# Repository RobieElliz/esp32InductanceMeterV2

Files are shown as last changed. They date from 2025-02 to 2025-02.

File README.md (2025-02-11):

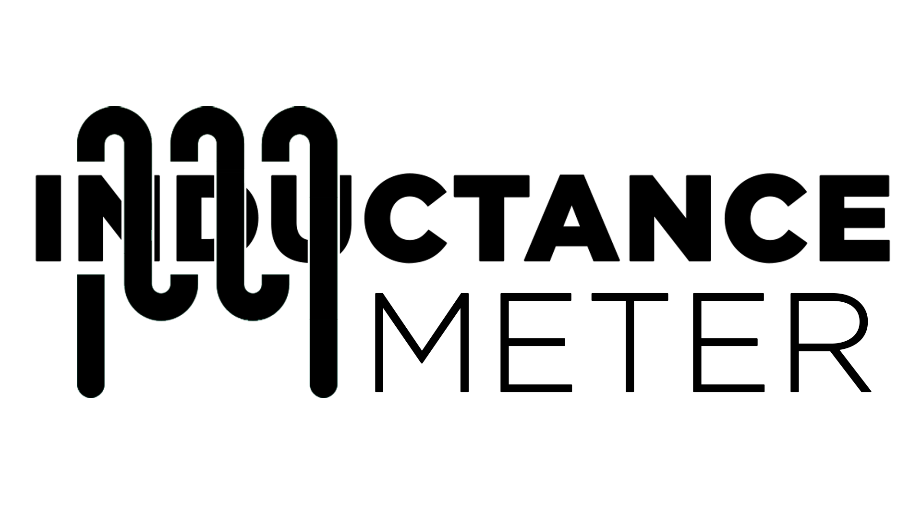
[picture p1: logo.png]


# Portable ESP32 Inductance Meter

A DIY ESP32-based inductance meter designed to bridge the gap in electronics testing. Developed at the Polytechnic University of the Philippines, this low-cost, high-precision tool is ideal for students, researchers, and hobbyists.

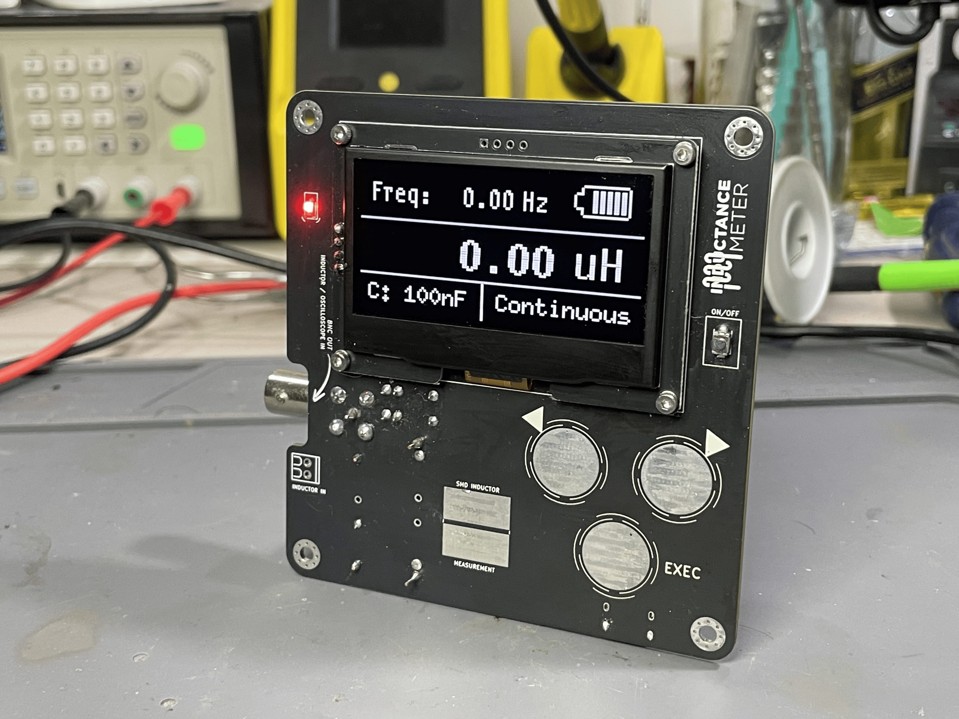
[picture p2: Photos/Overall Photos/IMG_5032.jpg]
Inductance Meter Overview


---

## 🔧 Bridging the Gap in Electronics Testing

Accurate inductance measurement is crucial in electronics. Yet, professional meters are often expensive and inaccessible. This project provides an affordable alternative for educational and experimental applications.

---

## 🚀 What It Does

Using LC resonance principles, the device:
- Excites inductors and detects oscillations
- Calculates inductance with high accuracy
- Measures various types of inductors:
  - Toroidal
  - Power
  - Surface-mount (SMD)
  - Air-core  
- Employs dual reference capacitors (100nF & 5µF) for precise mH and µH readings

---

## 🛠 Key Features & Innovations

- **ESP32-powered processing** for real-time calculations  
- **Dual reference capacitors** to optimize accuracy  
- **Capacitive touch controls** for seamless operation  
- **Rechargeable 18650 battery** for true portability  
- **OLED display** for clear, instant readings  
- **Multiple measurement modes:** Single or continuous testing

---

## 📌 Why It Matters

By democratizing access to essential testing equipment, this project empowers the next generation of engineers to innovate and experiment without breaking the bank.

---

## Detailed Components

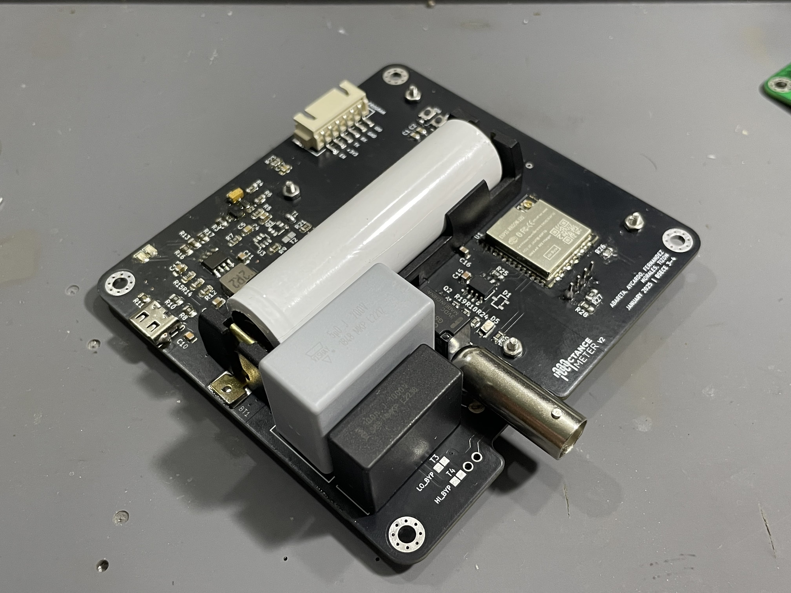
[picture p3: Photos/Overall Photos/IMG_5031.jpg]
Detailed Components


### 🔧 Dual Reference Capacitors (100nF & 5µF)
- **100nF:** For higher inductance (mH range) with enhanced accuracy  
- **5µF:** Ideal for lower inductance (µH range) ensuring frequency stability

### 🟢 TLV3202 Comparator
- Ultra-high-speed and low-power
- Ensures precise detection of LC oscillations

### ⚡ IP2312 Battery Management IC
- Supports USB Type-C charging (5V, up to 3A)
- Provides overvoltage, undervoltage, and overcurrent protection
- Delivers a stable 3.3V output with buck-boost regulation

### 📟 2.4-inch OLED Display
- Connected via I²C for reduced wiring complexity
- Stacked on the PCB using screws for a compact design
- Displays real-time inductance, frequency, and battery status

---

## Additional Resources

- **OLED Module Purchase:**  
  [Shopee: 2.4" 2.42 inch 128x64 OLED LCD Display Module SSD1309](https://shopee.ph/2.4-2.42-inch-128x64-OLED-LCD-Display-Module-SSD1309-12864-7-Pin-SPI-IIC-I2C-Serial-Interface-for-Arduino-UNO-R3-C51-i.517103615.18774113725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)

---

## License

This project is open source. See the [LICENSE](LICENSE) file for more details.

---

## Made By

This project is made by:  
Johanna Abareta, Ken Louise Aycardo, Katrina Dianne Fernandez, Vince Morales, Robie Elliz Tizon

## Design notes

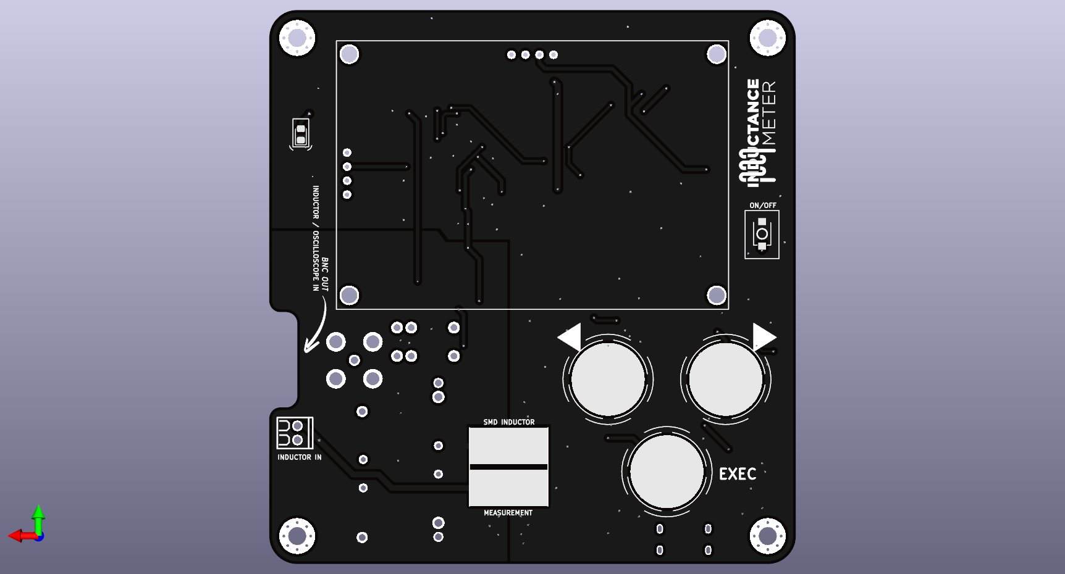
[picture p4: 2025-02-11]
Photos/KiCad PCB Photos/Front-Bare.png

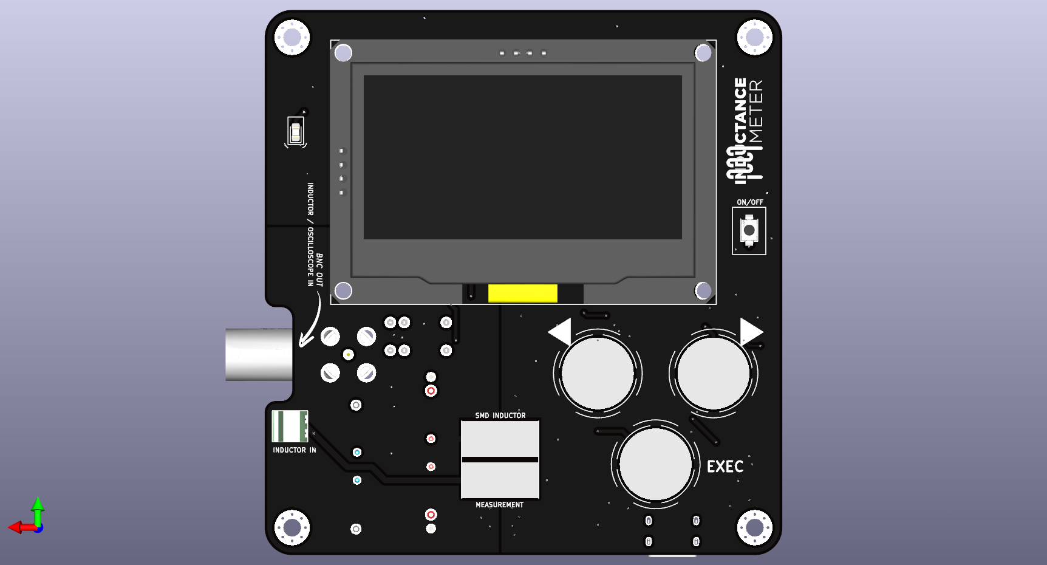
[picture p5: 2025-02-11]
Photos/KiCad PCB Photos/Front.png

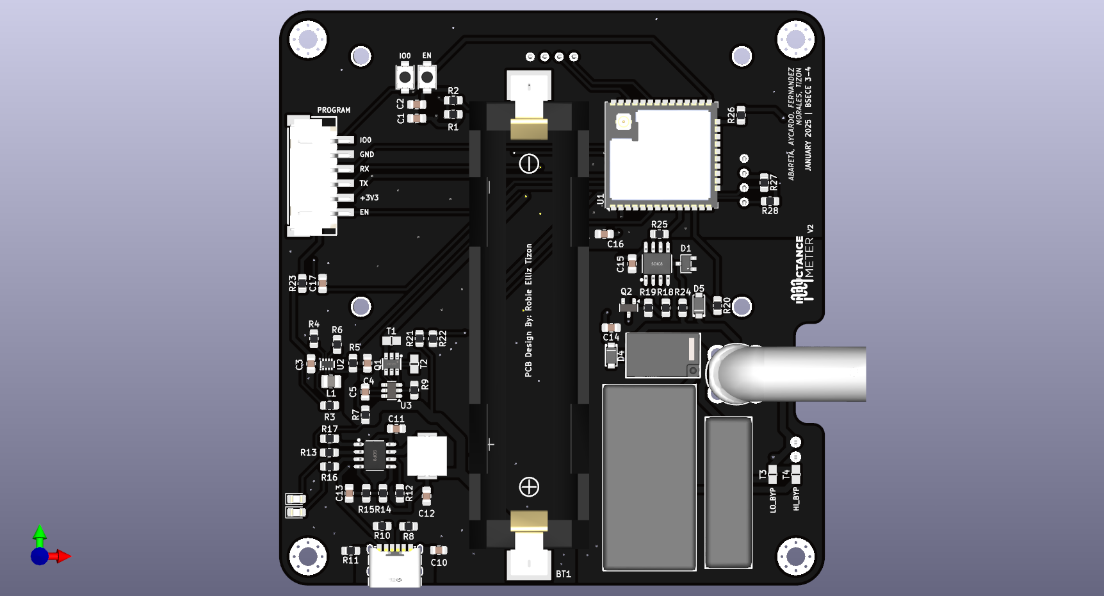
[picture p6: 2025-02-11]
Photos/KiCad PCB Photos/Back.png

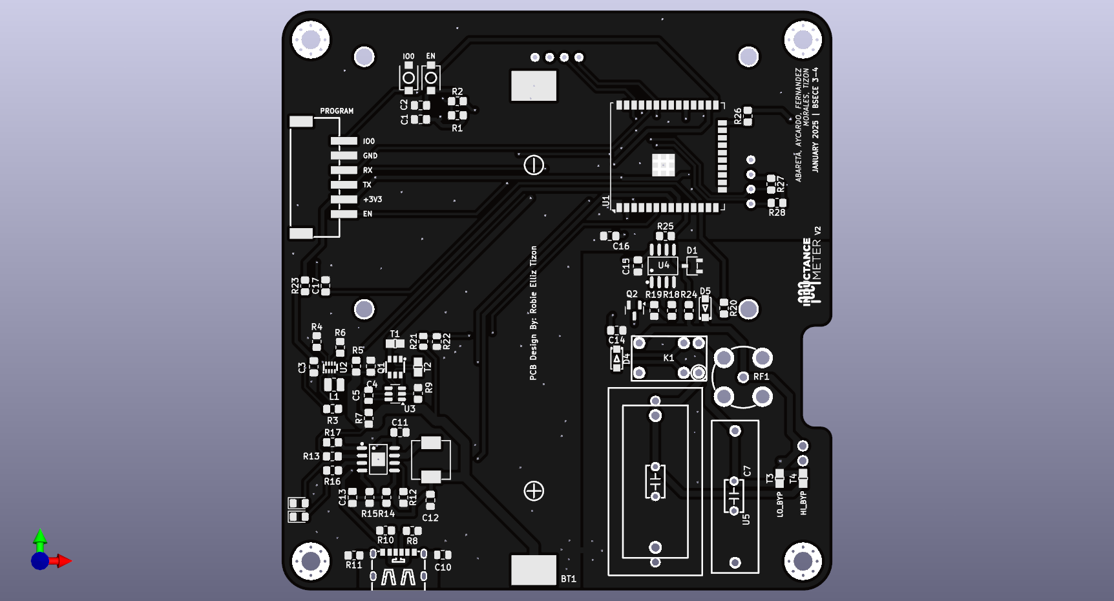
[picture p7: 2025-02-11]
Photos/KiCad PCB Photos/Back-Bare.png

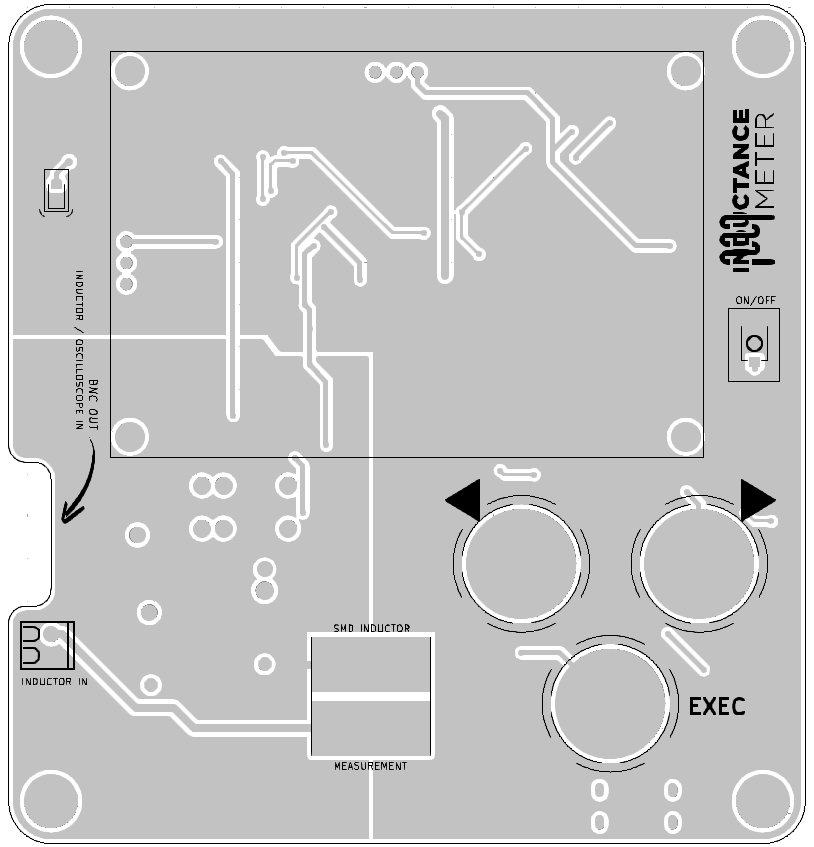
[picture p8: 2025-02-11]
Photos/KiCad PCB Photos/Front PCB Layout.png

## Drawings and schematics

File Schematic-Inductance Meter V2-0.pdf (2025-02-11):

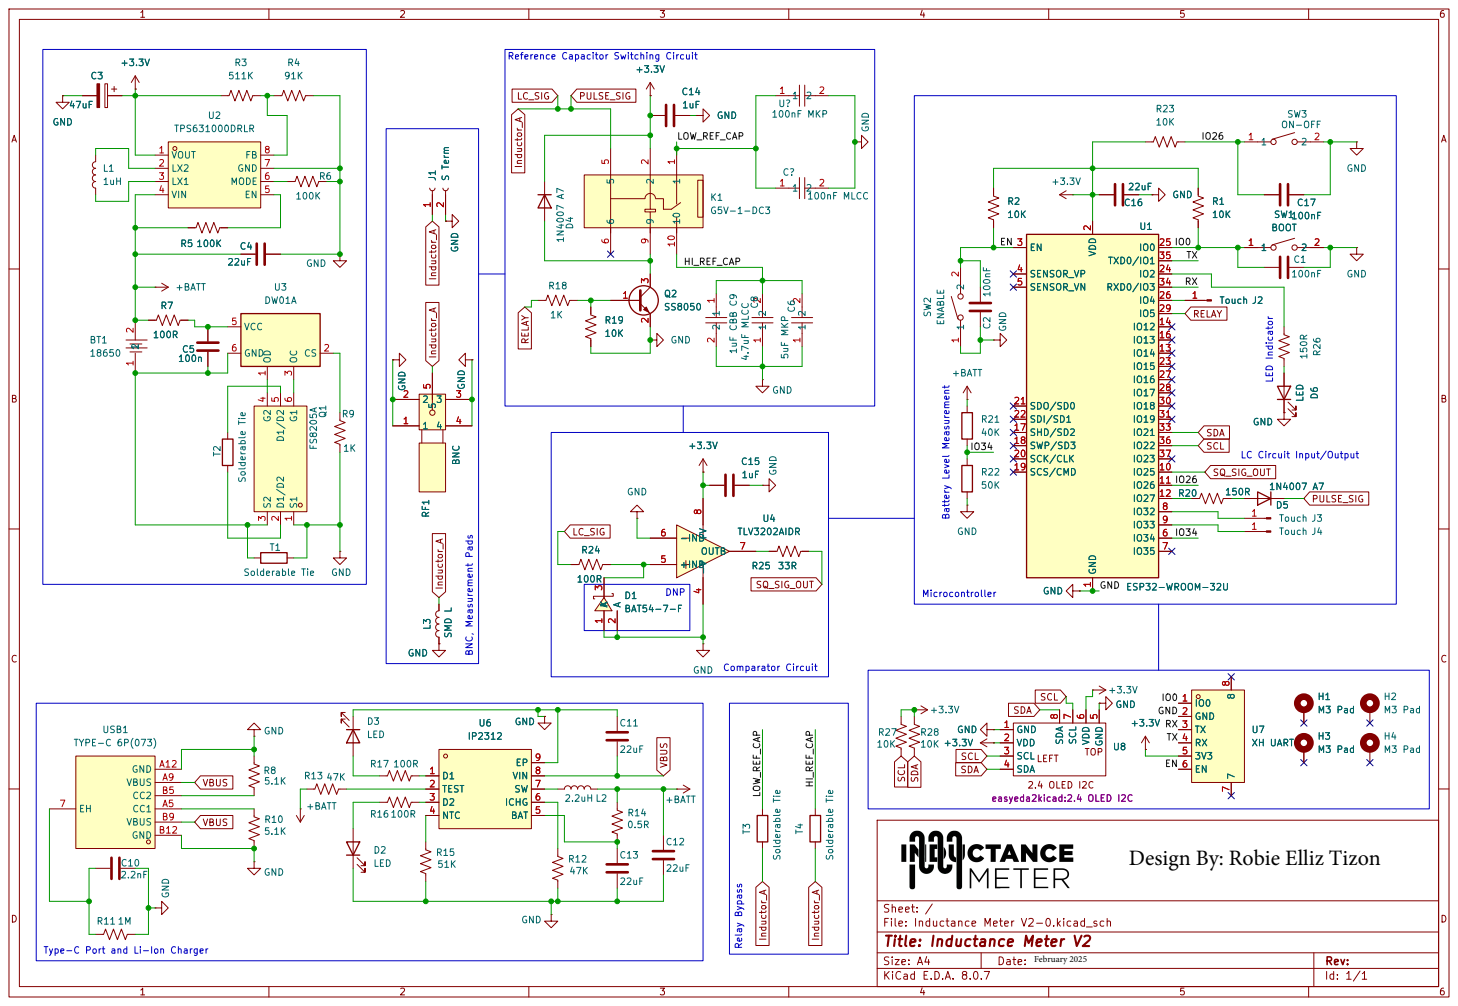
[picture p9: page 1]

2 SCK/CLK 20 SDO/SD0 21 SDI/SD1 22

Design By: Robie Elliz Tizon

Id: 1/1 Title: Inductance Meter V2

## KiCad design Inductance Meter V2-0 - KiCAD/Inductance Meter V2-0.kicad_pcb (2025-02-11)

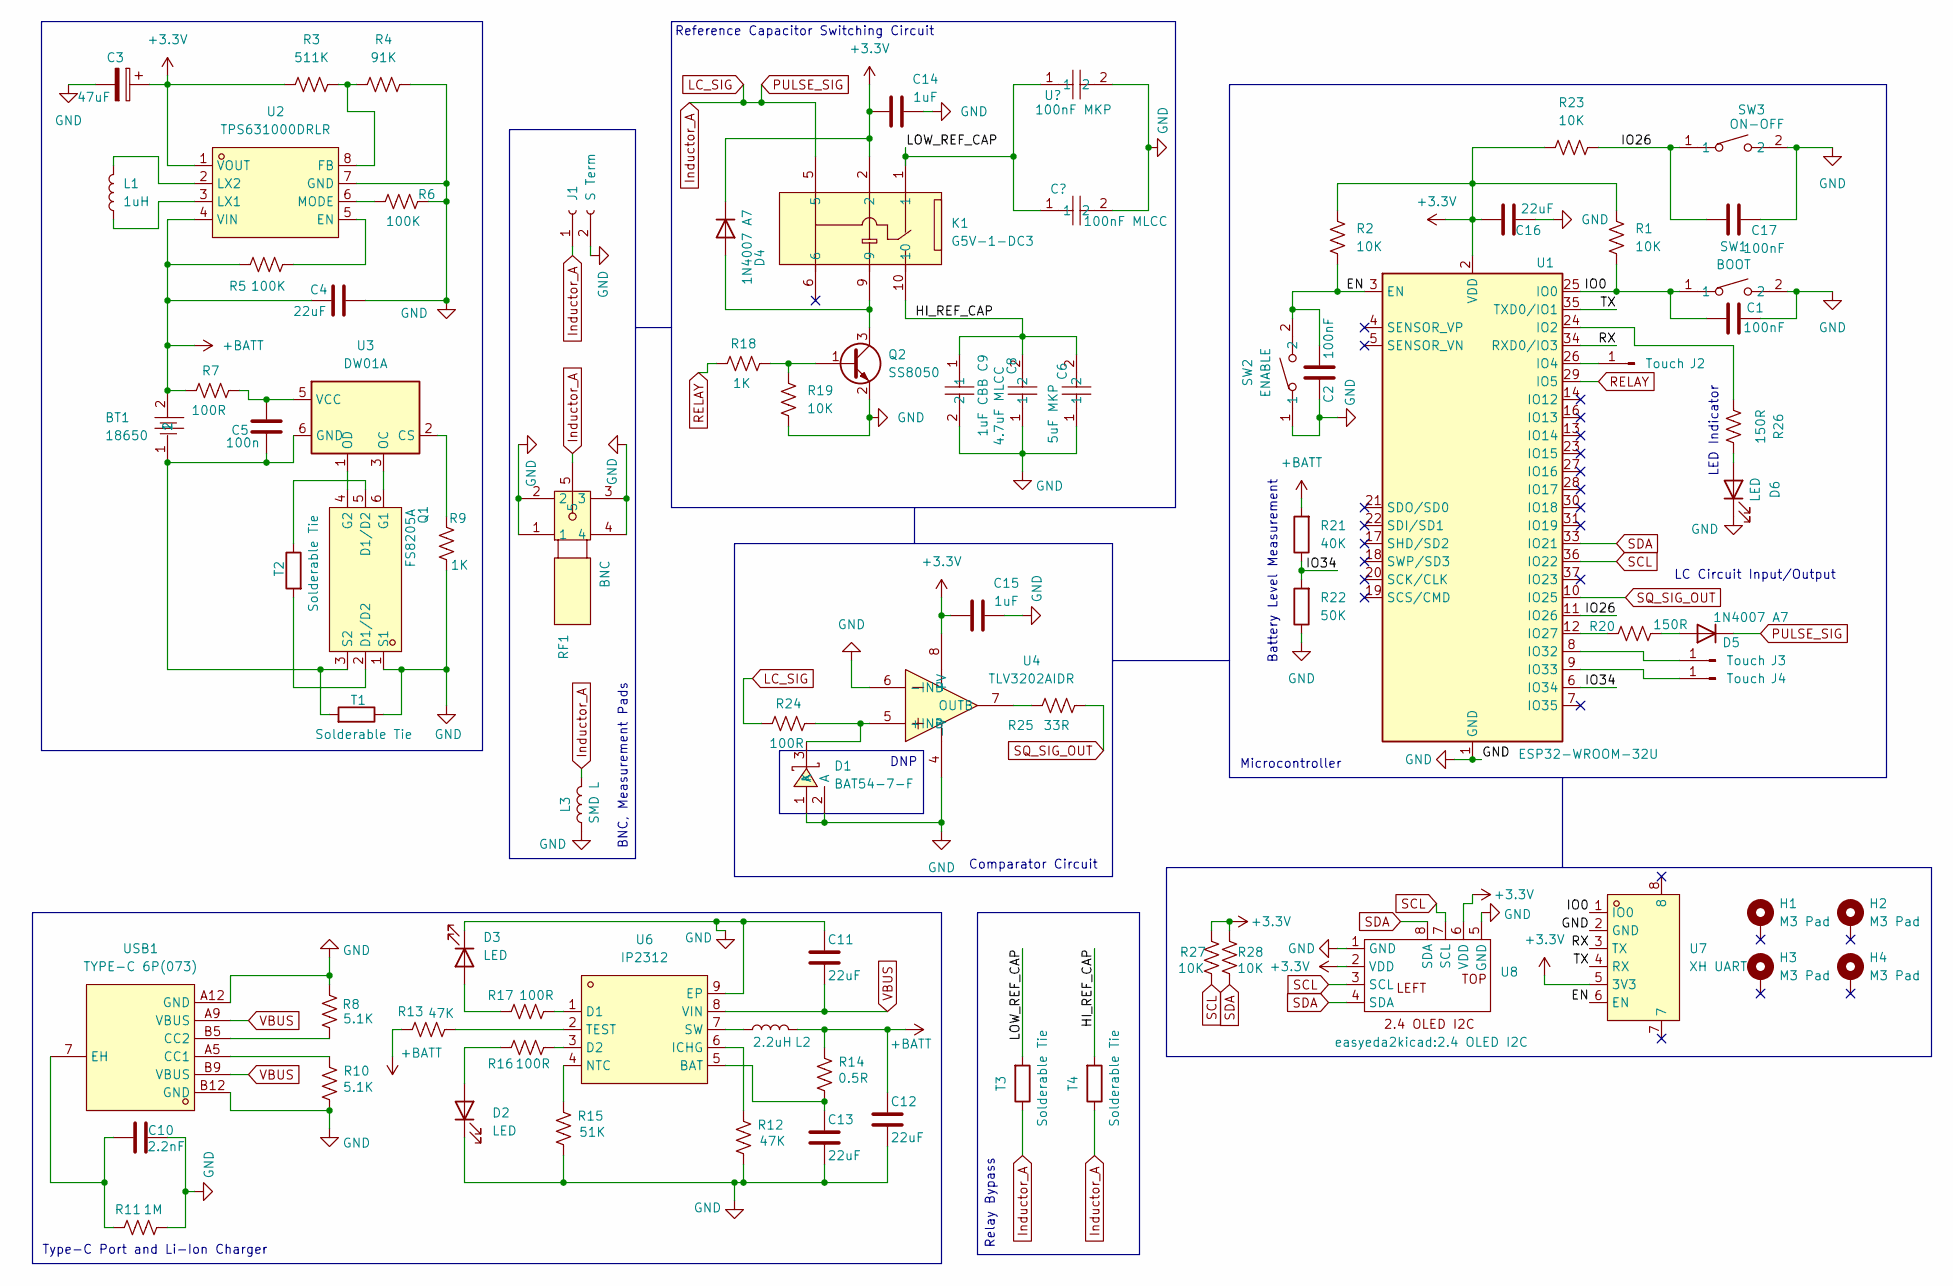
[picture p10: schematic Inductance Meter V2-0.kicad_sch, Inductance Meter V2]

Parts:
BT1: 18650; BATTERY-SMD_18650-1S-L77.1-W20.7-1; LCSC Part C2988620
C1, C2, C17: 100nF; C_0805_2012Metric_Pad1.18x1.45mm_HandSolder
C3: 47uF; C_0805_2012Metric_Pad1.18x1.45mm_HandSolder
C4, C11, C12, C13, C16: 22uF; C_0805_2012Metric_Pad1.18x1.45mm_HandSolder
C5: 100n; C_0805_2012Metric
C6: 5uF MKP; CAP-TH_L32.0-W16.0-P27.50-D0.8; LCSC Part C3803313
C8: 4.7uF MLCC; CAP-TH_L5.5-W3.2-P5.00-D0.5; LCSC Part C907942
C9: 1uF CBB; CAP-TH_L26.0-W11.1-P22.50-D1.4; LCSC Part C178465
C10: 2.2nF; C_0805_2012Metric
C14, C15: 1uF; C_0805_2012Metric_Pad1.18x1.45mm_HandSolder
D1: BAT54-7-F; SOT-23-3_L2.9-W1.6-P1.90-LS2.8-BR; LCSC Part C106920
D2, D3, D6: LED; LED_0805_2012Metric_Pad1.15x1.40mm_HandSolder
D4, D5: 1N4007 A7; SOD-123FL_L2.8-W1.8-LS3.7-RD
H1, H2, H3, H4: M3 Pad; MountingHole_3.2mm_M3_Pad_Via
J1: S Term; CONN-TH_2P-P2.54_MX128-2.54-GN01-02P-CU-Y-A
J2, J3, J4: Touch; Touch_Pad_ESP
K1: G5V-1-DC3; RELAY-TH_G5V-1; LCSC Part C397232
L1: 1uH; L_1008_2520Metric
L2: 2.2uH; IND-SMD_L7.1-W6.6; LCSC Part C2847481
L3: SMD L; IND-SMD_L7.1-W6.6; LCSC Part C2847481
Q1: FS8205A; SOT-23-6_L2.9-W1.6-P0.95-LS2.8-BR; LCSC Part C2830320
Q2: SS8050; SOT-23
R1, R2, R19, R23, R27, R28: 10K; R_0805_2012Metric_Pad1.20x1.40mm_HandSolder
R3: 511K; R_0805_2012Metric_Pad1.20x1.40mm_HandSolder
R4: 91K; R_0805_2012Metric_Pad1.20x1.40mm_HandSolder
R5, R6: 100K; R_0805_2012Metric_Pad1.20x1.40mm_HandSolder
R7, R16, R17, R24: 100R; R_0805_2012Metric_Pad1.20x1.40mm_HandSolder
R8, R10: 5.1K; R_0805_2012Metric_Pad1.20x1.40mm_HandSolder
R9, R18: 1K; R_0805_2012Metric_Pad1.20x1.40mm_HandSolder
R11: 1M; R_0805_2012Metric_Pad1.20x1.40mm_HandSolder
R12, R13: 47K; R_0805_2012Metric_Pad1.20x1.40mm_HandSolder
R14: 0.5R; R_0805_2012Metric_Pad1.20x1.40mm_HandSolder
R15: 51K; R_0805_2012Metric_Pad1.20x1.40mm_HandSolder
R20, R26: 150R; R_0805_2012Metric_Pad1.20x1.40mm_HandSolder
R21: 40K; R_0805_2012Metric
R22: 50K; R_0805_2012Metric
R25: 33R; R_0805_2012Metric_Pad1.20x1.40mm_HandSolder
RF1: BNC; BNC-TH_DOSIN-801-0051; LCSC Part C521210
SW1: BOOT; SW-SMD_L3.9-W3.0-P4.45; LCSC Part C720477
SW2: ENABLE; SW-SMD_L3.9-W3.0-P4.45; LCSC Part C720477
SW3: ON-OFF; SW-SMD_L3.9-W3.0-P4.45; LCSC Part C720477
T1, T2, T3, T4: Solderable Tie; Net-Tie 0805 Based
U1: ESP32-WROOM-32U
U2: TPS631000DRLR; SOT-583-8_L2.1-W1.2-P0.50-LS1.6-BL; LCSC Part C5219190
U3: DW01A; SOT-23-6
U4: TLV3202AIDR; SOIC-8_L4.9-W3.9-P1.27-LS6.0-BL; LCSC Part C129325
U6: IP2312; SOP-8_L4.9-W3.9-P1.27-LS6.0-BL-EP; LCSC Part C605432
U7: XH UART; CONN-SMD_S6B-XH-SM4-TB-LF-SN; LCSC Part C191914
U8: 2.4 OLED I2C
USB1: TYPE-C 6P(073); TYPE-C-SMD_TYPE-C-6P_5; LCSC Part C668623

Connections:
+3.3V: C3.1, C14.2, C15.2, C16.2, D4.1 (K), K1.2, R1.1, R2.1, R3.1, R23.2, R27.1, R28.1, U1.2 (VDD), U2.1 (VOUT), U4.8 (+V), U7.5 (3V3), U8.2 (VDD), U8.6 (VDD)
+BATT: BT1.2, C4.1, C12.2, L2.2, R5.1, R7.1, R13.1, R14.1, R21.2, U2.4 (VIN)
/EN: C2.2, R2.2, SW2.2, U1.3 (EN), U7.6 (EN)
/HI_REF_CAP: C6.2, C8.2, C9.1, K1.10, T4.1
/IO0: C1.1, R1.2, SW1.1, U1.25 (IO0), U7.1 (IO0)
/IO2: R26.1, U1.24 (IO2)
/IO26: C17.1, R23.1, SW3.1, U1.11 (IO26)
/IO34: R21.1, R22.2, U1.6 (IO34)
/LOW_REF_CAP: K1.1, T3.1; also elsewhere on the board
/RX: U1.34 (RXD0/IO3), U7.3 (TX)
/TX: U1.35 (TXD0/IO1), U7.4 (RX)
GND: C1.2, C2.1, C3.2, C4.2, C6.1, C8.1, C9.2, C10.2, C11.2, C12.1, C13.1, C14.1, C15.1, C16.1, C17.2, D1.1 (A), D1.2 (A), D2.1 (K), D3.1 (K), D6.1 (K), J1.2, L3.1, Q1.1 (S1), Q2.2 (E), R4.2, R6.2, R8.2, R9.2, R10.2, R11.2, R12.2, R15.2, R19.1, R22.1, RF1.1, RF1.2, RF1.3, RF1.4, SW1.2, SW2.1, SW3.2, T1.2, U1.1 (GND), U1.15 (GND), U1.38 (GND), U1.39 (GND), U2.7 (GND), U4.4 (-V), U4.6 (-INB), U6.9 (EP), U7.2 (GND), U8.1 (GND), U8.5 (GND), USB1.A12 (GND), USB1.B12 (GND); also elsewhere on the board
Inductor_A: D5.1 (K), J1.1, K1.5, L3.2, R24.1, RF1.5, T3.2, T4.2
unnamed: D1.3 (K), R24.2, U4.5 (+INB)
unnamed: D2.2 (A), R16.1
unnamed: D3.2 (A), R17.1
unnamed: D4.2 (A), K1.9, Q2.3 (C)
unnamed: D5.2 (A), R20.2
unnamed: D6.2 (A), R26.2
unnamed: J2.1, U1.26 (IO4)
unnamed: J3.1, U1.8 (IO32)
unnamed: J4.1, U1.9 (IO33)
unnamed: Q1.2 (D1/D2), T2.1
unnamed: Q1.5 (D1/D2), T2.2
unnamed: Q1.6 (G1), U3.3 (OC)
unnamed: Q1.4 (G2), U3.1 (OD)
unnamed: BT1.1, C5.2, Q1.3 (S2), T1.1, U3.6 (GND)
unnamed: Q2.1 (B), R18.2, R19.2
unnamed: R20.1, U1.12 (IO27)
unnamed: R5.2, U2.5 (EN)
unnamed: R3.2, R4.1, U2.8 (FB)
unnamed: L1.1, U2.3 (LX1)
unnamed: L1.2, U2.2 (LX2)
unnamed: R6.1, U2.6 (MODE)
unnamed: R9.1, U3.2 (CS)
unnamed: C5.1, R7.2, U3.5 (VCC)
unnamed: R25.1, U4.7 (OUTB)
unnamed: C13.2, R14.2, U6.5 (BAT)
unnamed: R17.2, U6.1 (D1)
unnamed: R16.2, U6.3 (D2)
unnamed: R12.1, U6.6 (ICHG)
unnamed: R15.1, U6.4 (NTC)
unnamed: L2.1, U6.7 (SW)
unnamed: R13.2, U6.2 (TEST)
unnamed: R10.1, USB1.A5 (CC1)
unnamed: R8.1, USB1.B5 (CC2)
unnamed: C10.1, R11.1, USB1.7 (EH)
RELAY: R18.1, U1.29 (IO5)
SCL: R27.2, U1.36 (IO22), U8.3 (SCL), U8.7 (SCL)
SDA: R28.2, U1.33 (IO21), U8.4 (SDA), U8.8 (SDA)
SQ_SIG_OUT: R25.2, U1.10 (IO25)
VBUS: C11.1, U6.8 (VIN), USB1.A9 (VBUS), USB1.B9 (VBUS)

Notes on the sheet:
LC Circuit Input/Output
Reference Capacitor Switching Circuit
Battery Level Measurement
BNC, Measurement Pads
Type-C Port and Li-Ion Charger
Microcontroller
Comparator Circuit
Relay Bypass
DNP
LED Indicator

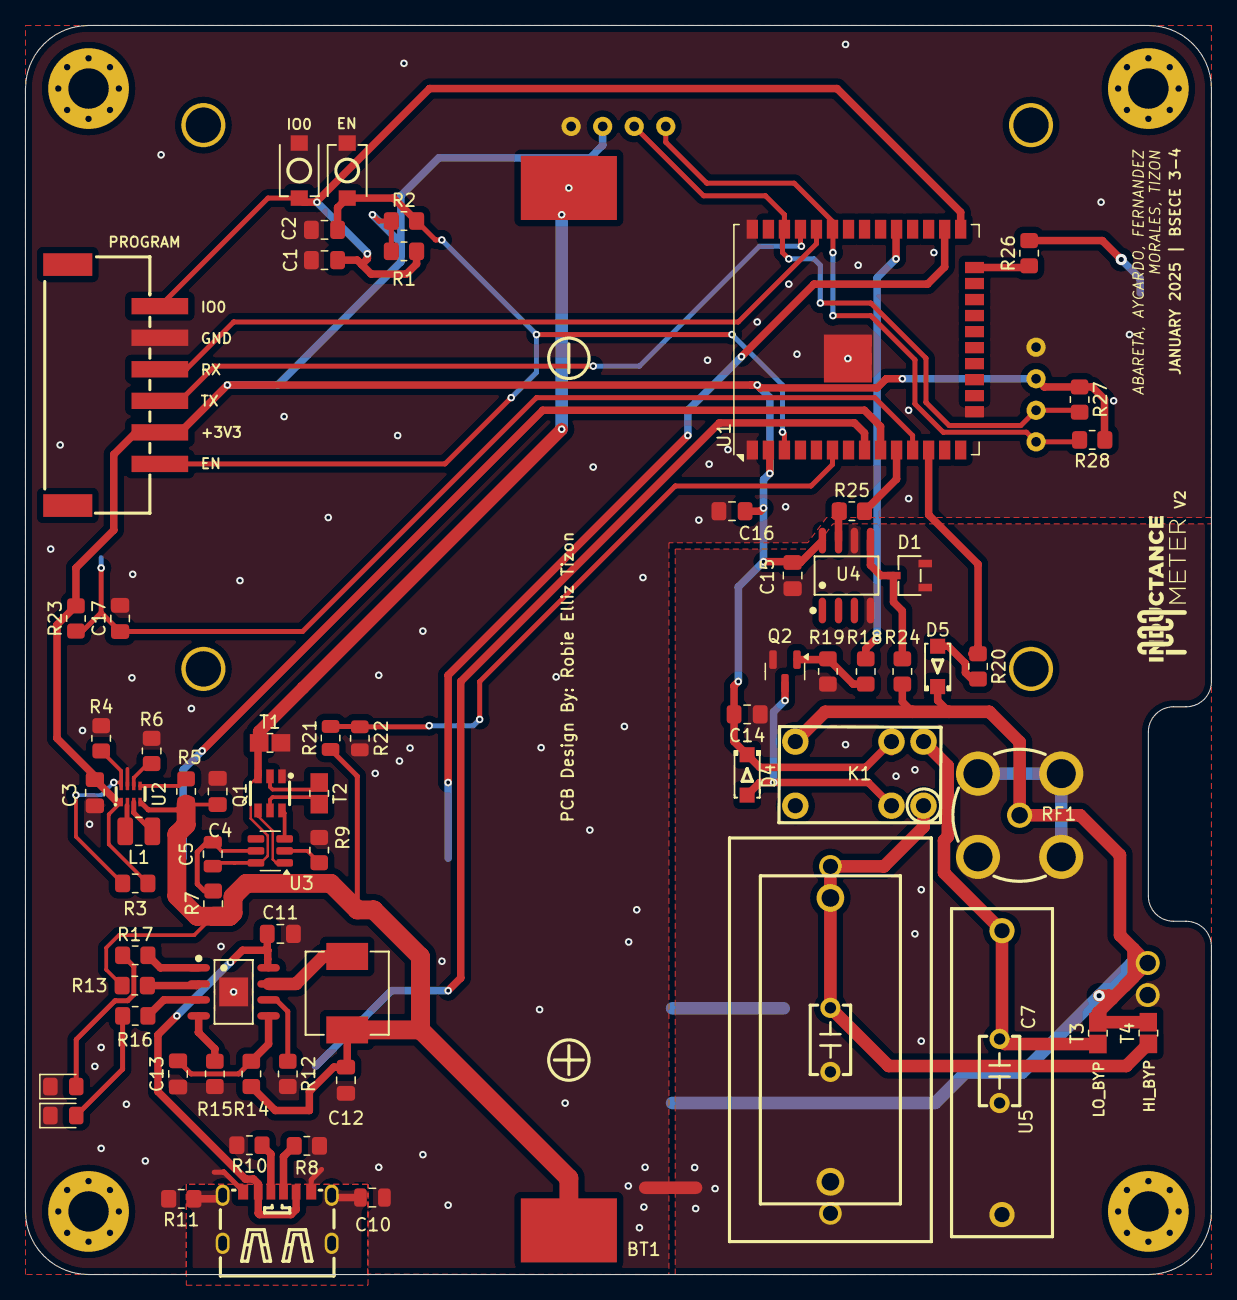
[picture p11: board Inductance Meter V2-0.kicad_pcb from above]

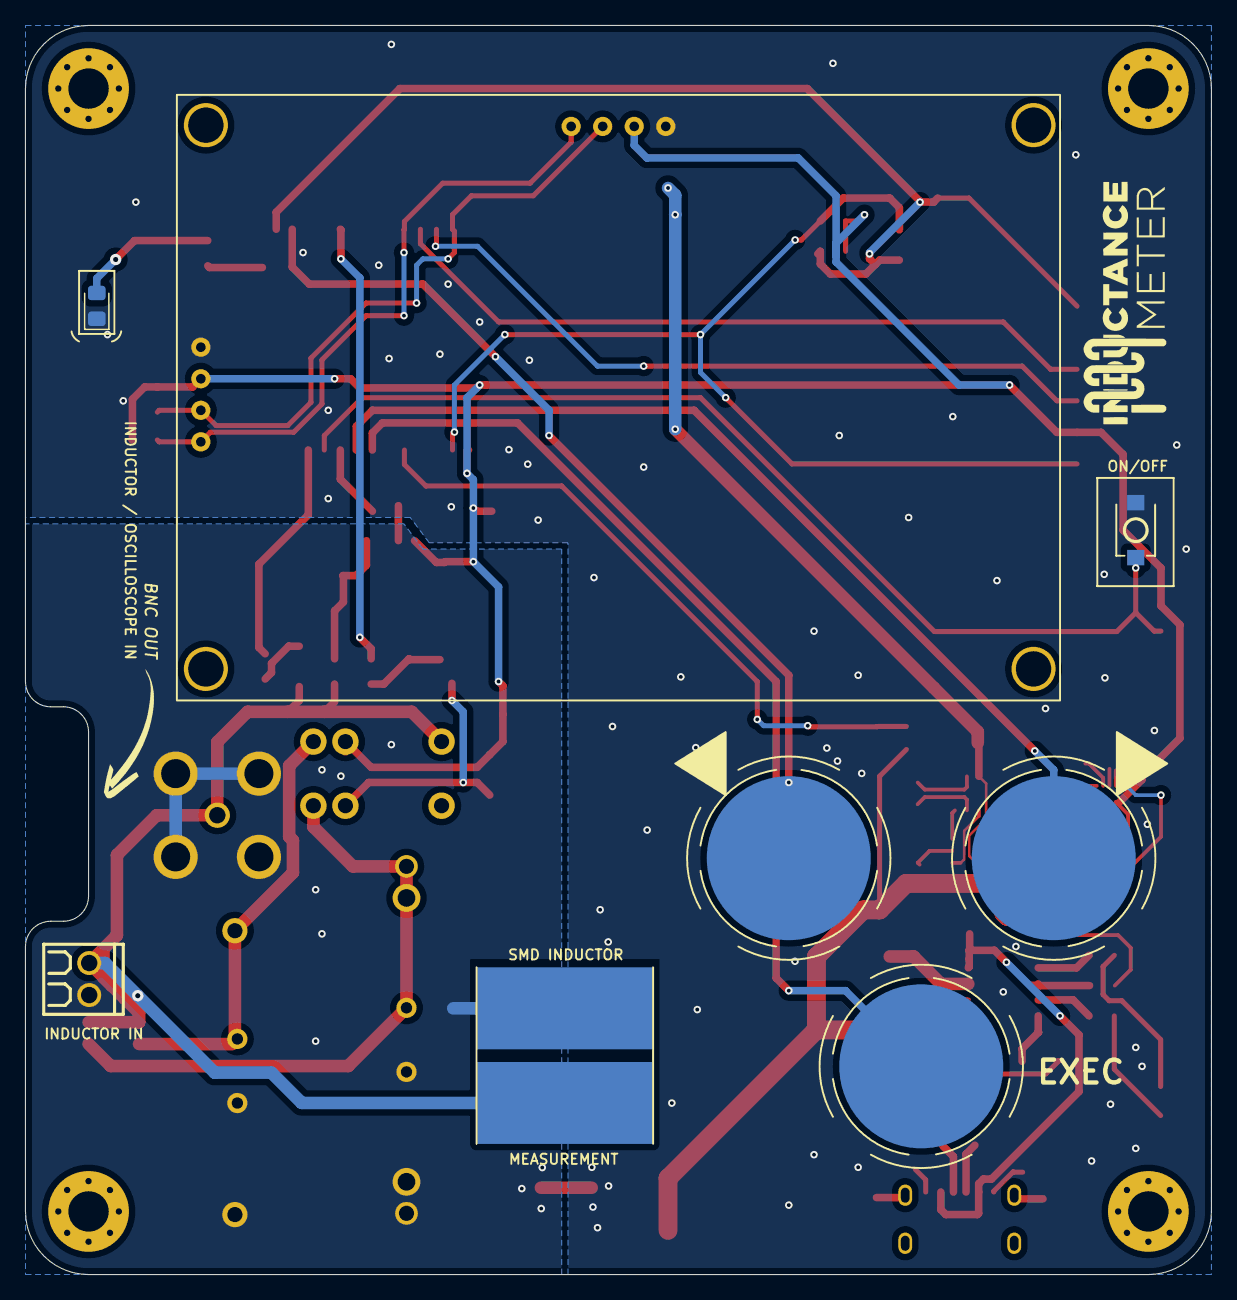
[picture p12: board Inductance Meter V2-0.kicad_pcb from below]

Board: 2 copper layers, 94.0 x 99.0 mm, 83 parts (8 on the bottom side), 52 nets.

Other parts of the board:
C7: 100nF MLCC; CAP-TH_L5.5-W3.2-P5.00-D0.5
U5: 100nF MKP; CAP-TH_L26.0-W8.0-P22.50-D0.8

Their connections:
/LOW_REF_CAP: C7.1, U5.1; also elsewhere on the board
GND: C7.2, U5.2; also elsewhere on the board

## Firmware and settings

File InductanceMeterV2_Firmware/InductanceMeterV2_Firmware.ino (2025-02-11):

#include <U8g2lib.h>
#include <Wire.h>
#include <esp_sleep.h>

// OLED configuration
U8G2_SSD1309_128X64_NONAME0_F_HW_I2C u8g2(U8G2_R0);

// Define pins
const int PIN_OUT = 27;    // ESP32 output pin to your circuit
const int PIN_IN = 25;     // ESP32 input pin from comparator/op-amp
const int BUTTON_PIN = 26; // Button to toggle sleep mode
const int LED_PIN = 2;     // LED to indicate measurement in progress
const int TOUCH_PIN = 4;    // ESP32 touch pin (GPIO4)
const int OUTPUT_PIN = 5;   // Output pin to change state on touch
String capacitance = "100nF";


// Mode state
String mode = "Continuous"; // Current mode: "Continuous" or "Single"

// Define second touch pin
const int TOUCH_PIN2 = 33;    // ESP32 touch pin (GPIO33)

// Define third touch pin
const int TOUCH_PIN3 = 32;    // ESP32 touch pin (GPIO32)

// Debounce parameters for TOUCH_PIN3
bool lastTouchState3 = false;    // Tracks the previous touch state for TOUCH_PIN3
unsigned long lastDebounceTime3 = 0; // Tracks the last debounce time for TOUCH_PIN3

// Debounce variables for BUTTON_PIN
bool lastButtonState = HIGH;                // Tracks the previous button state (HIGH = not pressed)
unsigned long lastButtonDebounceTime = 0;   // Tracks the last debounce time for BUTTON_PIN


// Flag to indicate if a single measurement has been done in Single Mode
bool singleMeasurementDone = false;


const int NUM_SAMPLES = 10;
const float DIFF_RATIO = 0.05f;


// Capacitor value (in Farads)
float CAPACITOR_VALUE = 100e-9; // 100nF

//Voltage Read Inputs
const int ANALOG_PIN = 34;          // Analog input pin
const float ADC_RESOLUTION = 4095; // ESP32 ADC resolution (12-bit)
const float VREF = 3.3;            // Reference voltage for ADC in volts
const float R1 = 40000.0;          // Resistor R1 in ohms
const float R2 = 50000.0;          // Resistor R2 in ohms
// Variables for long press detection
unsigned long buttonPressStartTime = 0; // Time when button was pressed
bool buttonHeld = false;                // Flag to indicate if button is held
const unsigned long LONG_PRESS_DURATION = 3000; // 3 seconds

// Battery voltage thresholds (in volts)
const float BATTERY_FULL = 4.2;
const float BATTERY_EMPTY = 3.0;

// Hysteresis threshold for transitions
const float HYSTERESIS = 0.05; // 0.05V tolerance

// Touch threshold (adjust based on your setup)
const int TOUCH_THRESHOLD = 40; // Lower values detect lighter touches

// Debounce parameters
const unsigned long DEBOUNCE_DELAY = 200; // 200 ms debounce

// Debounce parameters for TOUCH_PIN2
bool lastTouchState2 = false;    // Tracks the previous touch state for TOUCH_PIN2
unsigned long lastDebounceTime2 = 0; // Tracks the last debounce time for TOUCH_PIN2

// Variables for touch handling
bool lastTouchState = false;    // Tracks the previous touch state
bool outputState = false;       // Tracks the current state of OUTPUT_PIN
unsigned long lastDebounceTime = 0; // Tracks the last time a touch was detected

// Global variables to store measurement results
bool validMeasurement = false;
float frequency = 0.0;      // Frequency in Hz
float inductance = 0.0;     // Inductance in Henry
float inductanceu = 0.0;    // Inductance in microHenries

static const unsigned char image_logo_bits[] = {0x00,0x00,0x00,0x00,0x00,0x00,0x00,0x00,0x00,0x00,0x00,0x00,0x00,0x00,0x00,0x00,0x00,0x00,0x00,0x00,0x00,0x00,0x00,0x00,0x00,0x00,0x00,0x00,0x00,0x00,0x00,0x00,0x00,0x00,0x00,0x00,0x00,0x00,0x00,0x00,0x00,0x00,0x00,0x00,0x00,0x00,0x00,0x00,0x00,0x00,0x00,0x00,0x00,0x00,0x00,0x00,0x00,0x00,0x00,0x00,0x00,0x00,0x00,0x00,0x00,0x00,0x00,0x00,0x00,0x00,0x00,0x00,0x00,0x00,0x00,0x00,0x00,0x00,0x00,0x00,0x00,0x00,0x00,0x00,0x00,0x00,0x00,0x00,0x00,0x00,0x00,0x00,0x00,0x00,0x00,0x00,0x00,0x00,0x00,0x00,0x00,0x00,0x00,0x00,0x00,0x00,0x00,0x00,0x00,0x00,0x00,0x00,0x00,0x00,0x00,0x00,0x00,0x00,0x00,0x00,0x00,0x00,0x00,0x00,0x00,0x00,0x00,0x00,0x00,0x00,0x00,0x00,0x00,0x00,0x00,0x00,0x00,0x00,0x00,0x00,0x00,0x00,0x00,0x00,0x00,0x00,0x00,0x00,0x00,0x00,0x00,0x00,0x00,0x00,0x00,0x00,0x00,0x00,0x00,0x00,0x00,0x00,0x00,0x00,0x00,0x00,0x00,0x00,0x00,0x00,0x00,0x00,0x00,0x00,0x00,0x00,0x00,0x00,0x00,0x00,0x00,0x78,0x80,0x07,0x3c,0x00,0x00,0x00,0x00,0x00,0x00,0x00,0x00,0x00,0x00,0x00,0xfc,0xe1,0x0f,0x7e,0x00,0x00,0x00,0x00,0x00,0x00,0x00,0x00,0x00,0x00,0x00,0xfe,0xf1,0x1f,0xff,0x00,0x00,0x00,0x00,0x00,0x00,0x00,0x00,0x00,0x00,0x00,0xfe,0xf3,0x9f,0xff,0x01,0x00,0x00,0x00,0x00,0x00,0x00,0x00,0x00,0x00,0x00,0xce,0xf3,0x9c,0xe7,0x01,0x00,0x00,0x00,0x00,0x00,0x00,0x00,0x00,0x00,0x00,0xce,0xf3,0x9c,0xe7,0x01,0x00,0x00,0x00,0x00,0x00,0x00,0x00,0x00,0x00,0x00,0xce,0xf3,0x9c,0xe7,0x01,0x00,0x00,0x00,0x00,0x00,0x00,0x00,0x00,0x00,0x00,0xc0,0x03,0x1c,0xe0,0x01,0x00,0x00,0x00,0x00,0x00,0x00,0x00,0x00,0x00,0x00,0xc0,0x03,0x1c,0xe0,0x01,0x07,0x00,0x70,0x00,0x00,0xe0,0x00,0x00,0x00,0x78,0xce,0xe7,0x1f,0xef,0xc7,0x9f,0xff,0xf1,0xe0,0x70,0xf8,0xf3,0x1f,0x00,0x78,0xde,0xe7,0x3f,0xef,0xe7,0xbf,0xff,0xf9,0xe0,0x71,0xfc,0xf7,0x1f,0x00,0x78,0xfe,0xe7,0x7c,0xef,0xf7,0x19,0x1c,0xf8,0xe1,0x73,0x9e,0x73,0x00,0x00,0x78,0xfe,0xe7,0x7c,0xef,0xf7,0x00,0x1c,0xf8,0xe1,0x77,0x0e,0x71,0x00,0x00,0x78,0xfe,0xe7,0x7c,0xef,0x77,0x00,0x1c,0xdc,0xe1,0x7f,0x0e,0xf0,0x0f,0x00,0x78,0xfe,0xe7,0x7c,0xef,0x77,0x00,0x1c,0xdc,0xe3,0x7f,0x0e,0xf0,0x0f,0x00,0x78,0xee,0xe7,0x7c,0xef,0xf7,0x00,0x1c,0xfe,0xe3,0x7e,0x0e,0x71,0x00,0x00,0x78,0xce,0xe7,0x3f,0xfe,0xe3,0x3d,0x1c,0xfe,0xe7,0x7c,0xbe,0x73,0x00,0x00,0x78,0xce,0xe7,0x3f,0xfe,0xe3,0x3f,0x1c,0x0f,0xe7,0x78,0xfc,0xf7,0x1f,0x00,0x78,0xce,0xe7,0x1f,0xfc,0xc1,0x1f,0x1c,0x07,0xe7,0x70,0xf8,0xf3,0x1f,0x00,0x00,0xc0,0x03,0x1c,0xe0,0x01,0x02,0x00,0x00,0x00,0x00,0x40,0x00,0x00,0x00,0x00,0xc0,0x03,0x1c,0xe0,0x01,0x00,0x00,0x00,0x00,0x00,0x00,0x00,0x00,0x00,0x00,0xce,0xf3,0x9c,0xe7,0x01,0x00,0x00,0x00,0x00,0x00,0x00,0x00,0x00,0x00,0x00,0xce,0xf3,0x9c,0xe7,0x01,0x00,0x00,0x00,0x00,0x00,0x00,0x00,0x00,0x00,0x00,0xce,0x7f,0xfc,0xe7,0x61,0x00,0xe1,0x3f,0xff,0xe3,0x1f,0xfe,0x00,0x00,0x00,0x8e,0x7f,0xfc,0xe3,0x61,0x80,0x21,0x00,0x10,0x20,0x00,0x02,0x03,0x00,0x00,0x0e,0x3f,0xf8,0xe1,0xa1,0xc0,0x21,0x00,0x10,0x20,0x00,0x02,0x02,0x00,0x00,0x0e,0x0c,0xe0,0xe0,0xa1,0x41,0x21,0x00,0x10,0x20,0x00,0x02,0x02,0x00,0x00,0x0e,0x00,0x00,0xe0,0x21,0x21,0x21,0x00,0x10,0x20,0x00,0x02,0x02,0x00,0x00,0x0e,0x00,0x00,0xe0,0x21,0x32,0x21,0x00,0x10,0x20,0x00,0x02,0x03,0x00,0x00,0x0e,0x00,0x00,0xe0,0x21,0x16,0xe1,0x1f,0x10,0xe0,0x1f,0xfe,0x01,0x00,0x00,0x0e,0x00,0x00,0xe0,0x21,0x0c,0x21,0x00,0x10,0x20,0x00,0x42,0x00,0x00,0x00,0x0e,0x00,0x00,0xe0,0x21,0x00,0x21,0x00,0x10,0x20,0x00,0xc2,0x00,0x00,0x00,0x0e,0x00,0x00,0xe0,0x21,0x00,0x21,0x00,0x10,0x20,0x00,0x82,0x01,0x00,0x00,0x0e,0x00,0x00,0xe0,0x21,0x00,0x21,0x00,0x10,0x20,0x00,0x02,0x01,0x00,0x00,0x0e,0x00,0x00,0xe0,0x21,0x00,0xe1,0x3f,0x10,0xe0,0x3f,0x02,0x02,0x00,0x00,0x0e,0x00,0x00,0xc0,0x00,0x00,0x00,0x00,0x00,0x00,0x00,0x00,0x00,0x00,0x00,0x00,0x00,0x00,0x00,0x00,0x00,0x00,0x00,0x00,0x00,0x00,0x00,0x00,0x00,0x00,0x00,0x00,0x00,0x00,0x00,0x00,0x00,0x00,0x00,0x00,0x00,0x00,0x00,0x00,0x00,0x00,0x00,0x00,0x00,0x00,0x00,0x00,0x00,0x00,0x00,0x00,0x00,0x00,0x00,0x00,0x00,0x00,0x00,0x00,0x00,0x00,0x00,0x00,0x00,0x00,0x00,0x00,0x00,0x00,0x00,0x00,0x00,0x00,0x00,0x00,0x00,0x00,0x00,0x00,0x00,0x00,0x00,0x00,0x00,0x00,0x00,0x00,0x00,0x00,0x00,0x00,0x00,0x00,0x00,0x00,0x00,0x00,0x00,0x00,0x00,0x00,0x00,0x00,0x00,0x00,0x00,0x00,0x00,0x00,0x00,0x00,0x00,0x00,0x00,0x00,0x00,0x00,0x00,0x00,0x00,0x00,0x00,0x00,0x00,0x00,0x00,0x00,0x00,0x00,0x00,0x00,0x00,0x00,0x00,0x00,0x00,0x00,0x00,0x00,0x00,0x00,0x00,0x00,0x00,0x00,0x00,0x00,0x00,0x00,0x00,0x00,0x00,0x00,0x00,0x00,0x00,0x00,0x00,0x00,0x00,0x00,0x00,0x00,0x00,0x00,0x00,0x00,0x00,0x00,0x00,0x00,0x00,0x00,0x00,0x00,0x00,0x00,0x00,0x00,0x00,0x00,0x00,0x00,0x00,0x00,0x00,0x00,0x00,0x00,0x00,0x00,0x00,0x00,0x00,0x00,0x00,0x00,0x00,0x00,0x00,0x00,0x00,0x00,0x00,0x00,0x00,0x00,0x00,0x00,0x00,0x00,0x00,0x00,0x00,0x00,0x00,0x00,0x00,0x00,0x00,0x00,0x00,0x00,0x00,0x00,0x00,0x00,0x00,0x00,0x00,0x00,0x00,0x00,0x00,0x00,0x00,0x00,0x00,0x00,0x00,0x00,0x00,0x00,0x00,0x00,0x00,0x00,0x00,0x00};
static const unsigned char image_battery_full_bits[] = {0x00,0x00,0x00,0xf0,0xff,0x7f,0x08,0x00,0x80,0x68,0xdb,0xb6,0x6e,0xdb,0xb6,0x61,0xdb,0xb6,0x61,0xdb,0xb6,0x61,0xdb,0xb6,0x61,0xdb,0xb6,0x61,0xdb,0xb6,0x6e,0xdb,0xb6,0x68,0xdb,0xb6,0x08,0x00,0x80,0xf0,0xff,0x7f,0x00,0x00,0x00,0x00,0x00,0x00};
static const unsigned char image_battery_83_bits[] = {0x00,0x00,0x00,0xf0,0xff,0x7f,0x08,0x00,0x80,0x08,0xdb,0xb6,0x0e,0xdb,0xb6,0x01,0xdb,0xb6,0x01,0xdb,0xb6,0x01,0xdb,0xb6,0x01,0xdb,0xb6,0x01,0xdb,0xb6,0x0e,0xdb,0xb6,0x08,0xdb,0xb6,0x08,0x00,0x80,0xf0,0xff,0x7f,0x00,0x00,0x00,0x00,0x00,0x00};
static const unsigned char image_battery_67_bits[] = {0x00,0x00,0x00,0xf0,0xff,0x7f,0x08,0x00,0x80,0x08,0xd8,0xb6,0x0e,0xd8,0xb6,0x01,0xd8,0xb6,0x01,0xd8,0xb6,0x01,0xd8,0xb6,0x01,0xd8,0xb6,0x01,0xd8,0xb6,0x0e,0xd8,0xb6,0x08,0xd8,0xb6,0x08,0x00,0x80,0xf0,0xff,0x7f,0x00,0x00,0x00,0x00,0x00,0x00};
static const unsigned char image_battery_50_bits[] = {0x00,0x00,0x00,0xf0,0xff,0x7f,0x08,0x00,0x80,0x08,0xc0,0xb6,0x0e,0xc0,0xb6,0x01,0xc0,0xb6,0x01,0xc0,0xb6,0x01,0xc0,0xb6,0x01,0xc0,0xb6,0x01,0xc0,0xb6,0x0e,0xc0,0xb6,0x08,0xc0,0xb6,0x08,0x00,0x80,0xf0,0xff,0x7f,0x00,0x00,0x00,0x00,0x00,0x00};
static const unsigned char image_battery_33_bits[] = {0x00,0x00,0x00,0xf0,0xff,0x7f,0x08,0x00,0x80,0x08,0x00,0xb6,0x0e,0x00,0xb6,0x01,0x00,0xb6,0x01,0x00,0xb6,0x01,0x00,0xb6,0x01,0x00,0xb6,0x01,0x00,0xb6,0x0e,0x00,0xb6,0x08,0x00,0xb6,0x08,0x00,0x80,0xf0,0xff,0x7f,0x00,0x00,0x00,0x00,0x00,0x00};
static const unsigned char image_battery_17_bits[] = {0x00,0x00,0x00,0xf0,0xff,0x7f,0x08,0x00,0x80,0x08,0x00,0xb0,0x0e,0x00,0xb0,0x01,0x00,0xb0,0x01,0x00,0xb0,0x01,0x00,0xb0,0x01,0x00,0xb0,0x01,0x00,0xb0,0x0e,0x00,0xb0,0x08,0x00,0xb0,0x08,0x00,0x80,0xf0,0xff,0x7f,0x00,0x00,0x00,0x00,0x00,0x00};
static const unsigned char image_battery_0_bits[] = {0x00,0x00,0x00,0xf0,0xff,0x7f,0x08,0x00,0x80,0x08,0x02,0x82,0x0e,0x04,0x81,0x01,0x88,0x80,0x01,0x50,0x80,0x01,0x20,0x80,0x01,0x50,0x80,0x01,0x88,0x80,0x0e,0x04,0x81,0x08,0x02,0x82,0x08,0x00,0x80,0xf0,0xff,0x7f,0x00,0x00,0x00,0x00,0x00,0x00};
static const unsigned char image_dolph_cry_bits[] = {0x00,0x00,0xf0,0x7f,0x00,0x00,0x00,0x00,0x00,0x0e,0x80,0x03,0x00,0x00,0x00,0x80,0x01,0x00,0x0c,0x00,0x00,0x00,0x60,0x00,0x00,0x30,0x00,0x00,0x00,0x10,0x00,0x00,0x40,0x00,0x00,0x00,0x08,0x00,0x00,0x80,0x00,0x00,0x00,0x04,0x00,0x00,0x00,0x01,0x00,0x00,0x02,0x00,0x00,0x00,0x02,0x00,0x00,0x01,0x00,0x00,0x00,0x04,0x00,0x80,0x00,0x00,0x00,0x00,0x08,0x00,0x80,0x00,0x00,0x00,0x00,0x08,0x00,0x40,0x00,0x00,0x00,0x00,0x10,0x00,0x40,0x00,0x00,0x00,0x00,0x10,0x00,0x20,0x00,0x00,0x00,0x00,0x20,0x00,0x20,0x00,0x00,0x00,0x00,0x20,0x00,0x10,0x00,0x00,0x00,0x00,0x20,0x00,0x10,0x00,0x00,0x00,0x00,0x40,0x00,0x10,0x00,0x00,0x20,0x00,0x40,0x00,0x08,0x00,0x00,0x1e,0x00,0x44,0x00,0x08,0x00,0x00,0x00,0x00,0x58,0x00,0x08,0x00,0x00,0x00,0x00,0x40,0x00,0x08,0x00,0x07,0x00,0x00,0x40,0x00,0x04,0x00,0x1f,0x00,0x00,0x40,0x00,0x04,0x00,0xff,0x07,0x00,0x66,0x00,0x04,0x80,0xff,0x07,0x00,0x7e,0x00,0x04,0x40,0xfd,0x07,0x00,0x7e,0x00,0x04,0x20,0xf9,0x01,0x70,0x7c,0x00,0x04,0x90,0x00,0x00,0x81,0x38,0x00,0x04,0x90,0x00,0x40,0x00,0x21,0x00,0x02,0x90,0x00,0x00,0x00,0x22,0x00,0x02,0x60,0x00,0x00,0x00,0x24,0x00,0x02,0x00,0x00,0x00,0x00,0x28,0x00,0x02,0x00,0x00,0x00,0x00,0x30,0x00,0x02,0x00,0x00,0x1e,0x00,0x60,0x00,0x02,0x00,0x00,0xe1,0x00,0xc0,0x00,0x02,0x00,0x08,0x00,0x03,0x80,0x00,0x01,0x00,0x08,0x00,0x0c,0x00,0x01,0x01,0x00,0x10,0x00,0x10,0x00,0x01,0x01,0x00,0x00,0x00,0x60,0x00,0x01,0x01,0x00,0x00,0x18,0x80,0x01,0x01,0x01,0x00,0x00,0x78,0x00,0xfe,0x00,0x01,0x00,0x00,0xf0,0x01,0x80,0x00,0x00,0x00,0x00,0xe0,0x0f,0x40,0x00,0x00,0x00,0x00,0xc0,0x7f,0x20,0x00,0x00,0x00,0x00,0x80,0xff,0x1f,0x00,0x00,0x00,0x00,0x00,0xff,0x0f,0x00,0x00,0x00,0x00,0x00,0xfe,0x07,0x00,0x00,0x00,0x00,0x00,0xf8,0x07,0x00,0x00,0x00,0x00,0x00,0xc0,0x07,0x00,0x00,0x00,0x00,0x00,0x00,0x02,0x00,0x00,0x00,0x00,0x00,0x00,0x02,0x00,0x00,0x00,0x00,0x00,0x00,0x02,0x00,0x00,0x00,0x00,0x00,0x00,0x02,0x00,0x00,0x00,0x00,0x00,0x00,0x02,0x00};
static const unsigned char image_cross_small_bits[] = {0x00,0x00,0x00,0x00,0x00,0x00,0x00,0x00,0x03,0x03,0x86,0x01,0xcc,0x00,0x78,0x00,0x30,0x00,0x78,0x00,0xcc,0x00,0x86,0x01,0x03,0x03,0x00,0x00,0x00,0x00,0x00,0x00};
static const unsigned char image_hour_glass_75_bits[] = {0xff,0x07,0x02,0x02,0x02,0x02,0x8a,0x02,0xfa,0x02,0x74,0x01,0xa8,0x00,0x50,0x00,0x50,0x00,0x88,0x00,0x24,0x01,0x22,0x02,0x72,0x02,0xfa,0x02,0xfe,0x03,0xff,0x07};
// New Image: Dolphin Common
static const unsigned char image_DolphinCommon_bits[] = {
  0x00,0x00,0x00,0x00,0xff,0x07,0x00,0x00,0x00,0x00,0xe0,0x01,0x3c,0x00,0x00,0x00,
  0x00,0x3c,0x00,0xe0,0x00,0x00,0x00,0x00,0x07,0x00,0x80,0x03,0x00,0x00,0x80,0x01,
  0x00,0x00,0x06,0x00,0x00,0xc0,0x00,0x00,0x00,0x0c,0x00,0x00,0x60,0x00,0x00,0x00,
  0x18,0x00,0x00,0x20,0x00,0x00,0x00,0x10,0x00,0x00,0x30,0x00,0x00,0x00,0x30,0x00,
  0x00,0x10,0x00,0x00,0x00,0x20,0x00,0x00,0x10,0x00,0x00,0x00,0x60,0x00,0x00,0x18,
  0x00,0x00,0x00,0x40,0x00,0x00,0x08,0x00,0x00,0x3f,0xc0,0x00,0x00,0x08,0x00,0x80,
  0x40,0x80,0x00,0x00,0x08,0x00,0x40,0xfe,0x80,0x00,0x00,0x0c,0x00,0x20,0xff,0x81,
  0x00,0x00,0x04,0x00,0xa0,0xf3,0x01,0x00,0x00,0x04,0x00,0xa0,0xf3,0x01,0xc0,0x03,
  0x04,0x00,0xa0,0xff,0x01,0x40,0x06,0x04,0x00,0xa0,0xff,0x01,0x40,0x04,0x04,0x00,
  0xa0,0xff,0x01,0x40,0x0c,0x0c,0x00,0x20,0xff,0x01,0x40,0x08,0x08,0x00,0x40,0x06,
  0x02,0x40,0x18,0xf8,0x03,0x80,0x03,0x04,0x40,0x10,0x0f,0x00,0x00,0x01,0x00,0x70,
  0xb0,0x01,0x00,0x00,0x20,0x00,0x1c,0x66,0x00,0x00,0x00,0x20,0x00,0x06,0x28,0x00,
  0x00,0x00,0x20,0x00,0x03,0x28,0x00,0x00,0x00,0x10,0x00,0x01,0x10,0x00,0x00,0x00,
  0x08,0x00,0x01,0x90,0x0f,0x00,0x00,0x06,0x00,0x01,0x50,0xf0,0x00,0xf0,0x01,0x00,
  0x05,0x28,0x00,0xff,0x0f,0x00,0x00,0x05,0x24,0x00,0x00,0x00,0x00,0x00,0x09,0x43,
  0x00,0x00,0x00,0x00,0x00,0xf3,0x80,0x01,0x00,0x00,0x00,0x06,0x80,0x0f,0x00,0x00,
  0x00,0x00,0x0c,0x80,0xf9,0x03,0x00,0x00,0x00,0x18,0x00,0x81,0xff,0x0f,0x00,0x00,
  0x10,0x00,0x81,0xff,0x07,0x00,0x00,0x10,0x00,0x81,0xff,0x03,0x00,0x00,0x10,0x00,
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
void loop() {
  // Handle button presses (short and long)
  handleButton();

    digitalWrite(LED_PIN, LOW); // Turn off LED after measurement


  // Check the current state
  if (currentState == NORMAL) {
    //////////////////////////////////////BATTERY HANDLE//////////////////////////////////////////

    // Read the raw ADC value from IO34
    int adcValue = analogRead(ANALOG_PIN);

    // Calculate the measured voltage at the ADC pin
    float voltageAtPin = (adcValue / ADC_RESOLUTION) * VREF;

    // Calculate the source voltage using the resistor network formula
    // Vsource = Vpin * (R1 + R2) / R2
    float batteryVoltage = (voltageAtPin * (R1 + R2) / R2) + 0.4;

    // Determine battery percentage
    float batteryPercentage = (batteryVoltage - BATTERY_EMPTY) / (BATTERY_FULL - BATTERY_EMPTY) * 100;
    batteryPercentage = constrain(batteryPercentage, 0, 100); // Clamp percentage between 0 and 100

    // Determine the appropriate battery image using hysteresis
    const unsigned char* newBatteryImage;
    if (batteryPercentage >= 83) {
      newBatteryImage = image_battery_full_bits;
    } else if (batteryPercentage >= 67) {
      newBatteryImage = image_battery_83_bits;
    } else if (batteryPercentage >= 50) {
      newBatteryImage = image_battery_67_bits;
    } else if (batteryPercentage >= 33) {
      newBatteryImage = image_battery_50_bits;
    } else if (batteryPercentage >= 17) {
      newBatteryImage = image_battery_33_bits;
    } else if (batteryPercentage > 0) {
      newBatteryImage = image_battery_17_bits;
    } else {
      newBatteryImage = image_battery_0_bits;
    }
    // Apply hysteresis: Change the image only if the voltage crosses the threshold by a significant margin
    if (currentBatteryImage != newBatteryImage) {
      if ((newBatteryImage == image_battery_full_bits && batteryVoltage >= (BATTERY_FULL - HYSTERESIS)) ||
          (newBatteryImage == image_battery_83_bits && batteryVoltage >= 3.9 && batteryVoltage < (BATTERY_FULL - HYSTERESIS)) ||
          (newBatteryImage == image_battery_67_bits && batteryVoltage >= 3.7 && batteryVoltage < 3.9) ||
          (newBatteryImage == image_battery_50_bits && batteryVoltage >= 3.5 && batteryVoltage < 3.7) ||
          (newBatteryImage == image_battery_33_bits && batteryVoltage >= 3.3 && batteryVoltage < 3.5) ||
          (newBatteryImage == image_battery_17_bits && batteryVoltage > BATTERY_EMPTY && batteryVoltage < 3.3) ||
          (newBatteryImage == image_battery_0_bits && batteryVoltage <= BATTERY_EMPTY)) {
        currentBatteryImage = newBatteryImage;
      }
    }

    // Handle all touch inputs
    handleTouch1(); // Handles touch on TOUCH_PIN (IO4)
    handleTouch2(); // Handles touch on TOUCH_PIN2 (IO33)
    handleTouch3(); // Handles touch on TOUCH_PIN3 (IO32)

    // Measurement Control Based on Mode
    if (mode == "Continuous") {
      measureInductance();
      singleMeasurementDone = false; // Reset flag when in Continuous mode
    } else if (mode == "Single") {
      if (singleMeasurementDone) {
        // Do nothing, keep displaying the last measurement
        // Measurement has already been done in handleTouch3()
      } else {
        // No measurement has been done, set frequency and inductance to 0
        frequency = 0.0;
        inductance = 0.0;
        inductanceu = 0.0;
      }
    }

    /// DISPLAY INFO////////////////////////////////////////////////////////////////////////

    u8g2.clearBuffer();
    u8g2.setFontMode(1);
    u8g2.setBitmapMode(1);

    u8g2.setFont(u8g2_font_6x10_tr);
    u8g2.drawStr(65, 59, mode.c_str());

    u8g2.drawStr(4, 59, ("C: " + capacitance).c_str());

    u8g2.setFont(u8g2_font_t0_12_tr);
    u8g2.drawStr(4, 16, "Freq:");

    // Draw lines for layout
    u8g2.drawLine(0, 47, 128, 47);
    u8g2.drawLine(58, 63, 58, 48);
    u8g2.drawLine(128, 23, 0, 23);

    // BATTERY LEVELS
    u8g2.drawXBM(98, 3, 24, 16, currentBatteryImage);

    // Prepare strings and units for display
    char inductanceStr[10]; // Buffer to store inductance as a string
    char frequencyStr[10];  // Buffer to store frequency as a string
    const char* inductanceUnit; // Pointer to store the inductance unit ("uH" or "mH")
    const char* frequencyUnit;  // Pointer to store the frequency unit ("Hz" or "kHz")
    float displayInductance;    // Adjusted inductance value for display
    float displayFrequency;     // Adjusted frequency value for display

    // --- Inductance Unit/Value ---

    // If inductanceu is in microhenries (µH):
    //  - >=1000 µH => mH
    //  - < 1.0 µH => nH
    //  - otherwise => keep in µH
    if (inductanceu >= 1000.0) {
      // convert µH to mH
      displayInductance = inductanceu / 1000.0;
      inductanceUnit = "mH";
    } else if (inductanceu < 1.0 && inductanceu > 0.0) {
      // convert µH to nH
      displayInductance = inductanceu * 1000.0;
      inductanceUnit = "nH";
    } else {
      // keep µH
      displayInductance = inductanceu;
      inductanceUnit = "uH";
    }

    // --- Frequency Unit/Value ---

    if (frequency > 999.99) {
      displayFrequency = frequency / 1000.0; // kHz
      frequencyUnit = "kHz";
    } else {
      displayFrequency = frequency; // Hz
      frequencyUnit = "Hz";
    }

    formatFiveDigits(displayInductance, inductanceStr, sizeof(inductanceStr));
    formatFiveDigits(displayFrequency, frequencyStr, sizeof(frequencyStr));

    // Now handle the drawing logic for Single vs Continuous mode
    if (mode == "Single") {
      if (!singleMeasurementDone) {
        // 1) Single mode, but no measurement has been done yet:
        //    => Show "Ready" (instead of "Error")
        u8g2.setFont(u8g2_font_t0_22b_tr);
        u8g2.drawStr(25, 43, "Ready");     // Instead of "Error"
        u8g2.setFont(u8g2_font_t0_22_tr);
        u8g2.drawStr(98, 42, "");

        // Show Frequency as "0.000 Hz"
        u8g2.setFont(u8g2_font_t0_12_tr);
        u8g2.drawStr(36, 16, "0.000");
        u8g2.drawStr(75, 16, "Hz");
      }
      else {
        // 2) Single mode, measurement was attempted (singleMeasurementDone == true)
        if (!validMeasurement) {
          // Measurement attempt returned invalid => "Error"
          u8g2.setFont(u8g2_font_t0_14b_tr);
          u8g2.drawStr(41, 40, "Pls Retry");
          u8g2.drawXBM(22, 27, 10, 16, image_cross_small_bits);

          // Clear or omit inductance unit
          u8g2.setFont(u8g2_font_t0_22_tr);
          u8g2.drawStr(98, 42, "");

          // Frequency => "0.000 Hz"
          u8g2.setFont(u8g2_font_t0_12_tr);
          u8g2.drawStr(36, 16, "0.000");
          u8g2.drawStr(75, 16, "Hz");
        }
        else {
          // 3) Single mode, valid measurement done => Show measurement
          // Inductance
          u8g2.setFont(u8g2_font_t0_22b_tr);
          u8g2.drawStr(25, 43, inductanceStr);
          u8g2.setFont(u8g2_font_t0_22_tr);
          u8g2.drawStr(98, 42, inductanceUnit);

          // Frequency
          u8g2.setFont(u8g2_font_t0_12_tr);
          u8g2.drawStr(36, 16, frequencyStr);
          u8g2.drawStr(75, 16, frequencyUnit);
        }
      }
    }
    else {
      // Continuous mode => always show measurement (or zero if not read)
      // Inductance
      u8g2.setFont(u8g2_font_t0_22b_tr);
      u8g2.drawStr(25, 43, inductanceStr);
      u8g2.setFont(u8g2_font_t0_22_tr);
      u8g2.drawStr(98, 42, inductanceUnit);

      // Frequency
      u8g2.setFont(u8g2_font_t0_12_tr);
      u8g2.drawStr(36, 16, frequencyStr);
      u8g2.drawStr(75, 16, frequencyUnit);
    }

    u8g2.sendBuffer();
  }
  else if (currentState == ABOUT) {
    // In ABOUT state, do not perform any other operations
    // The About screen is already displayed in showAboutScreen()
    // Optionally, you can add a delay or handle additional logic here
    // For now, do nothing
  }
}
